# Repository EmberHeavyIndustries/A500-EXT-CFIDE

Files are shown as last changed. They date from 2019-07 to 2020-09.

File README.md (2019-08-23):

**A500-EXT-CFIDE** is an external IDE + Fast Memory Expansion for Amiga 500. 

It is basically a modified clone of Matthias Heinrich's CDTV-RAM-IDE board, targeted to be a quick & dirt solution for external A500/A1000 bootable mass storage (with the bonus of a RAM expansion if fitted).

The firmware is a customized version of original Matthias code, and comes thank to the wonderful kindness of Matthias himself, who put the effort and coded this derivative one as well. Thanks Matthias ! 

Within repository full schematics, board, gerbers and firmware code can be found free for everyone.
Please note that rev.1.0 board (the current one) has not been optimized against design rules, so though the project has been tested and proved fully working, a further rev.1.1 board will be released in next future, addressing all desgin "misbehaviours".

**License**

**A500-EXT-CFIDE** is Open Hardware. If you make any modifications to the board, please contribute them back.
Any derivative work must quote both the original author (Matthias Heinrich aka Matze) and EmberHeavyIndustries.

**Disclaimer**

**A500-EXT-CFIDE** is provided to you 'as is' and without any express or implied warranties whatsoever with respect to its functionality, operability or use, including, without limitation, any implied warranties of merchantability, fitness for a particular purpose or infringement. We expressly disclaim any liability whatsoever for any direct, indirect, consequential, incidental or special damages, including, without limitation, lost revenues, lost profits, losses resulting from business interruption or loss of data, regardless of the form of action or legal theory under which the liability may be asserted, even if advised of the possibility or likelihood of such damages.

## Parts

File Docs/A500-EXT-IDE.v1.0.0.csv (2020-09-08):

Part | Value | Device | Package | Description | MF | MPN | OC_FARNELL | OC_NEWARK
AUTOBOOT_OFF |  | JP1E | JP1 | JUMPER
C1 | 100n | C-EUC0603K | C0603K | CAPACITOR, European symbol
C2 | 100n | C-EUC0603K | C0603K | CAPACITOR, European symbol
C3 | 10u | C-EUC0805K | C0805K | CAPACITOR, European symbol
C4 | 10u | C-EUC0805K | C0805K | CAPACITOR, European symbol
C5 | 100n | C-EUC0603K | C0603K | CAPACITOR, European symbol
C6 | 10u | C-EUC0805K | C0805K | CAPACITOR, European symbol
C7 | 100n | C-EUC0603K | C0603K | CAPACITOR, European symbol
C8 | 100n | C-EUC0603K | C0603K | CAPACITOR, European symbol
C9 | 100n | C-EUC0603K | C0603K | CAPACITOR, European symbol
C10 | 100n | C-EUC0603K | C0603K | CAPACITOR, European symbol
C11 | 100n | C-EUC0603K | C0603K | CAPACITOR, European symbol
C12 | 100n | C-EUC0603K | C0603K | CAPACITOR, European symbol
CN1 | A500-EXPANSION-SLOT-SOLDER | A500-EXPANSION-SLOT-SOLDER | LKONT_43-SLOT-SOLDER
IC2 | XC95288XL-TQ144 | XC95288XL-TQ144 | TQFP144
IC3 | 74HCT245PW | 74HCT245PW | TSSOP20 | Octal BUS TRANSCEIVER, 3-state
IC4 | 74HCT245PW | 74HCT245PW | TSSOP20 | Octal BUS TRANSCEIVER, 3-state
IC5 | 74HCT245PW | 74HCT245PW | TSSOP20 | Octal BUS TRANSCEIVER, 3-state
IC6 | AS4C4M16S-6TCN | AS4C4M16S-6TCN | TSOP-2_54
IC7 | LD117AS33TR | LD117AS33TR | SOT223 | Low drop fixed and adjustable positive voltage regulators 1 A
IC8 | AM29F010J-SOCKET | AM29F010J-SOCKET | PLCC-32-SMT-TT | 1-Megabit FLASH MEMORY
IC10 | 50MHz | CSX-750FCFC(5V) | 7X5 | CITIZEN Crystal Clock Oscilator from http://cfm.citizen.co.jp/english/product/pdf/CSX-750F.pdf
JP1 |  | JP1E | JP1 | JUMPER
JP2 |  | JP1E | JP1 | JUMPER
MEM_OFF |  | JP1E | JP1 | JUMPER
R1 | 330 | R-EU_R0603 | R0603 | RESISTOR, European symbol
R2 | 4.7k | R-EU_R0603 | R0603 | RESISTOR, European symbol
R3 | 4.7k | R-EU_R0603 | R0603 | RESISTOR, European symbol
R4 | 4.7k | R-EU_R0603 | R0603 | RESISTOR, European symbol
R5 | 4.7k | R-EU_R0603 | R0603 | RESISTOR, European symbol
R6 | 4.7k | R-EU_R0603 | R0603 | RESISTOR, European symbol
R7 | 750mA | R-EU_R2512 | R2512 | RESISTOR, European symbol
R8 | FERRITE | R-EU_R0603 | R0603 | RESISTOR, European symbol
R9 | 47 | R-EU_R0603 | R0603 | RESISTOR, European symbol
RN1 | 33 | 4R-NCAY16 | CAY16 | Array Chip Resistor |  |  | unknown | unknown
RN2 | 33 | 4R-NCAY16 | CAY16 | Array Chip Resistor |  |  | unknown | unknown
RN3 | 33 | 4R-NCAY16 | CAY16 | Array Chip Resistor |  |  | unknown | unknown
RN4 | 33 | 4R-NCAY16 | CAY16 | Array Chip Resistor |  |  | unknown | unknown
RN5 | 33 | 4R-NCAY16 | CAY16 | Array Chip Resistor |  |  | unknown | unknown
RN6 | 4.7k | 4R-NCAY16 | CAY16 | Array Chip Resistor |  |  | unknown | unknown
RN7 | 33 | 4R-NCAY16 | CAY16 | Array Chip Resistor |  |  | unknown | unknown
RN8 | 33 | 4R-NCAY16 | CAY16 | Array Chip Resistor |  |  | unknown | unknown
RN9 | 33 | 4R-NCAY16 | CAY16 | Array Chip Resistor |  |  | unknown | unknown
RN10 | 33 | 4R-NCAY16 | CAY16 | Array Chip Resistor |  |  | unknown | unknown
RN11 | 33 | 4R-NCAY16 | CAY16 | Array Chip Resistor |  |  | unknown | unknown
SV1 |  | ML40 | ML40 | HARTING |  |  | unknown | unknown
SV2 |  | ML10L | ML10L | HARTING |  |  | unknown | unknown

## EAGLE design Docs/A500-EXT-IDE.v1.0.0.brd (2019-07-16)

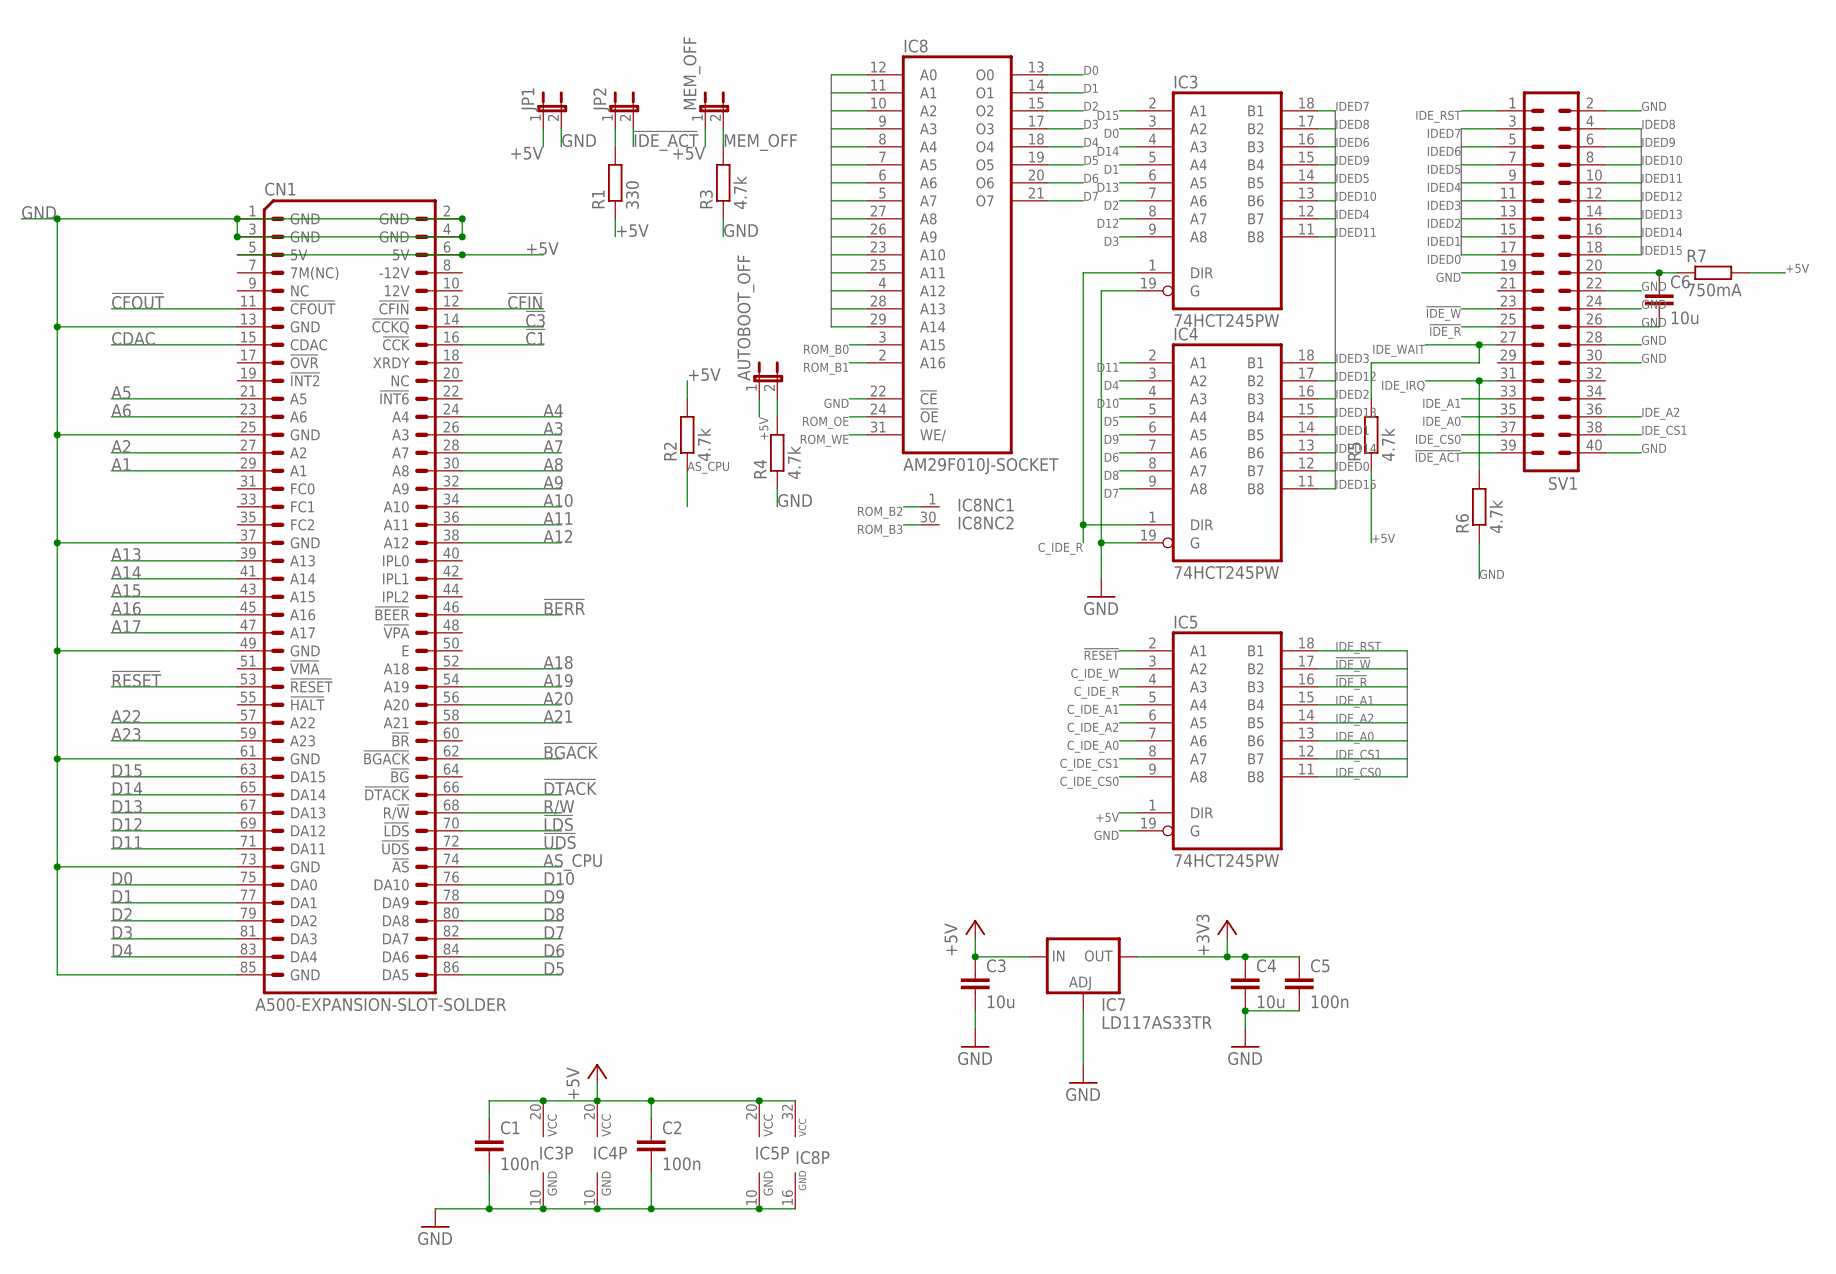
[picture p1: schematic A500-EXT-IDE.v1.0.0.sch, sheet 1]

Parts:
AUTOBOOT_OFF: JP1E; JP1
C1, C2, C5: 100n; C0603K
C3, C4, C6: 10u; C0805K
CN1: A500-EXPANSION-SLOT-SOLDER; LKONT_43-SLOT-SOLDER
IC3, IC4, IC5: 74HCT245PW; TSSOP20
IC7: LD117AS33TR; SOT223
IC8: AM29F010J-SOCKET; PLCC-32-SMT-TT
JP1, JP2: JP1E; JP1
MEM_OFF: JP1E; JP1
R1: 330; R0603
R2, R3, R4, R5, R6: 4.7k; R0603
R7: 750mA; R2512
SV1: ML40

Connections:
!BERR: CN1.46 (!BEER!); also elsewhere on the board
!BGACK: CN1.62 (!BGACK!); also elsewhere on the board
!C1: CN1.16 (!CCK!); also elsewhere on the board
!C3: CN1.14 (!CCKQ!); also elsewhere on the board
!CFIN: CN1.12 (!CFIN!); also elsewhere on the board
!CFOUT: CN1.11 (!CFOUT!); also elsewhere on the board
!DTACK: CN1.66 (!DTACK!); also elsewhere on the board
!IDE_ACT: JP2.2, SV1.39
!IDE_R: IC5.16 (B3), SV1.25
!IDE_W: IC5.17 (B2), SV1.23
!LDS: CN1.70 (!LDS!); also elsewhere on the board
!RESET: CN1.53 (!RESET!), IC5.2 (A1); also elsewhere on the board
!UDS: CN1.72 (!UDS!); also elsewhere on the board
+3V3: C4.1, C5.1, IC7.2 (OUT), IC7.4 (OUT); also elsewhere on the board
+5V: AUTOBOOT_OFF.1, C1.1, C2.1, C3.1, CN1.5 (5V), CN1.6 (5V), IC3.20 (VCC), IC4.20 (VCC), IC5.1 (DIR), IC5.20 (VCC), IC7.3 (IN), IC8.32 (VCC), JP1.1, MEM_OFF.1, R1.1, R2.2, R5.1, R7.2; also elsewhere on the board
A1: CN1.29 (A1), IC8.12 (A0); also elsewhere on the board
A2: CN1.27 (A2), IC8.11 (A1); also elsewhere on the board
A3: CN1.26 (A3), IC8.10 (A2); also elsewhere on the board
A4: CN1.24 (A4), IC8.9 (A3); also elsewhere on the board
A5: CN1.21 (A5), IC8.8 (A4); also elsewhere on the board
A6: CN1.23 (A6), IC8.7 (A5); also elsewhere on the board
A7: CN1.28 (A7), IC8.6 (A6); also elsewhere on the board
A8: CN1.30 (A8), IC8.5 (A7); also elsewhere on the board
A9: CN1.32 (A9), IC8.27 (A8); also elsewhere on the board
A10: CN1.34 (A10), IC8.26 (A9); also elsewhere on the board
A11: CN1.36 (A11), IC8.23 (A10); also elsewhere on the board
A12: CN1.38 (A12), IC8.25 (A11); also elsewhere on the board
A13: CN1.39 (A13), IC8.4 (A12); also elsewhere on the board
A14: CN1.41 (A14), IC8.28 (A13); also elsewhere on the board
A15: CN1.43 (A15), IC8.29 (A14); also elsewhere on the board
A16: CN1.45 (A16); also elsewhere on the board
A17: CN1.47 (A17); also elsewhere on the board
A18: CN1.52 (A18); also elsewhere on the board
A19: CN1.54 (A19); also elsewhere on the board
A20: CN1.56 (A20); also elsewhere on the board
A21: CN1.58 (A21); also elsewhere on the board
A22: CN1.57 (A22); also elsewhere on the board
A23: CN1.59 (A23); also elsewhere on the board
AS_CPU: CN1.74 (!AS!), R2.1; also elsewhere on the board
AUTO_BOOT_OFF: AUTOBOOT_OFF.2, R4.2; also elsewhere on the board
CDAC: CN1.15 (CDAC); also elsewhere on the board
C_IDE_A0: IC5.7 (A6); also elsewhere on the board
C_IDE_A1: IC5.5 (A4); also elsewhere on the board
C_IDE_A2: IC5.6 (A5); also elsewhere on the board
C_IDE_CS0: IC5.9 (A8); also elsewhere on the board
C_IDE_CS1: IC5.8 (A7); also elsewhere on the board
C_IDE_R: IC3.1 (DIR), IC4.1 (DIR), IC5.4 (A3); also elsewhere on the board
C_IDE_W: IC5.3 (A2); also elsewhere on the board
D0: CN1.75 (DA0), IC3.3 (A2), IC8.13 (O0); also elsewhere on the board
D1: CN1.77 (DA1), IC3.5 (A4), IC8.14 (O1); also elsewhere on the board
D2: CN1.79 (DA2), IC3.7 (A6), IC8.15 (O2); also elsewhere on the board
D3: CN1.81 (DA3), IC3.9 (A8), IC8.17 (O3); also elsewhere on the board
D4: CN1.83 (DA4), IC4.3 (A2), IC8.18 (O4); also elsewhere on the board
D5: CN1.86 (DA5), IC4.5 (A4), IC8.19 (O5); also elsewhere on the board
D6: CN1.84 (DA6), IC4.7 (A6), IC8.20 (O6); also elsewhere on the board
D7: CN1.82 (DA7), IC4.9 (A8), IC8.21 (O7); also elsewhere on the board
D8: CN1.80 (DA8), IC4.8 (A7); also elsewhere on the board
D9: CN1.78 (DA9), IC4.6 (A5); also elsewhere on the board
D10: CN1.76 (DA10), IC4.4 (A3); also elsewhere on the board
D11: CN1.71 (DA11), IC4.2 (A1); also elsewhere on the board
D12: CN1.69 (DA12), IC3.8 (A7); also elsewhere on the board
D13: CN1.67 (DA13), IC3.6 (A5); also elsewhere on the board
D14: CN1.65 (DA14), IC3.4 (A3); also elsewhere on the board
D15: CN1.63 (DA15), IC3.2 (A1); also elsewhere on the board
GND: C1.2, C2.2, C3.2, C4.2, C5.2, C6.2, CN1.1 (GND), CN1.2 (GND), CN1.3 (GND), CN1.4 (GND), CN1.13 (GND), CN1.25 (GND), CN1.37 (GND), CN1.49 (GND), CN1.61 (GND), CN1.73 (GND), CN1.85 (GND), IC3.10 (GND), IC3.19 (G), IC4.10 (GND), IC4.19 (G), IC5.10 (GND), IC5.19 (G), IC7.1 (ADJ), IC8.16 (GND), IC8.22 (!CE), JP1.2, R3.1, R4.1, R6.1, SV1.2, SV1.19, SV1.22, SV1.24, SV1.26, SV1.28, SV1.30, SV1.40; also elsewhere on the board
IDED0: IC4.12 (B7), SV1.17
IDED1: IC4.14 (B5), SV1.15
IDED2: IC4.16 (B3), SV1.13
IDED3: IC4.18 (B1), SV1.11
IDED4: IC3.12 (B7), SV1.9
IDED5: IC3.14 (B5), SV1.7
IDED6: IC3.16 (B3), SV1.5
IDED7: IC3.18 (B1), SV1.3
IDED8: IC3.17 (B2), SV1.4
IDED9: IC3.15 (B4), SV1.6
IDED10: IC3.13 (B6), SV1.8
IDED11: IC3.11 (B8), SV1.10
IDED12: IC4.17 (B2), SV1.12
IDED13: IC4.15 (B4), SV1.14
IDED14: IC4.13 (B6), SV1.16
IDED15: IC4.11 (B8), SV1.18
IDE_A0: IC5.13 (B6), SV1.35
IDE_A1: IC5.15 (B4), SV1.33
IDE_A2: IC5.14 (B5), SV1.36
IDE_CS0: IC5.11 (B8), SV1.37
IDE_CS1: IC5.12 (B7), SV1.38
IDE_IRQ: R6.2, SV1.31; also elsewhere on the board
IDE_RST: IC5.18 (B1), SV1.1
IDE_WAIT: R5.2, SV1.27; also elsewhere on the board
KEY_PIN_POWER: C6.1, R7.1, SV1.20
MEM_OFF: MEM_OFF.2, R3.2; also elsewhere on the board
unnamed: JP2.1, R1.2
R/W: CN1.68 (R/!W!); also elsewhere on the board
ROM_B0: IC8.3 (A15); also elsewhere on the board
ROM_B1: IC8.2 (A16); also elsewhere on the board
ROM_B2: IC8.1 (NC); also elsewhere on the board
ROM_B3: IC8.30 (NC); also elsewhere on the board
ROM_OE: IC8.24 (!OE); also elsewhere on the board
ROM_WE: IC8.31 (WE/); also elsewhere on the board

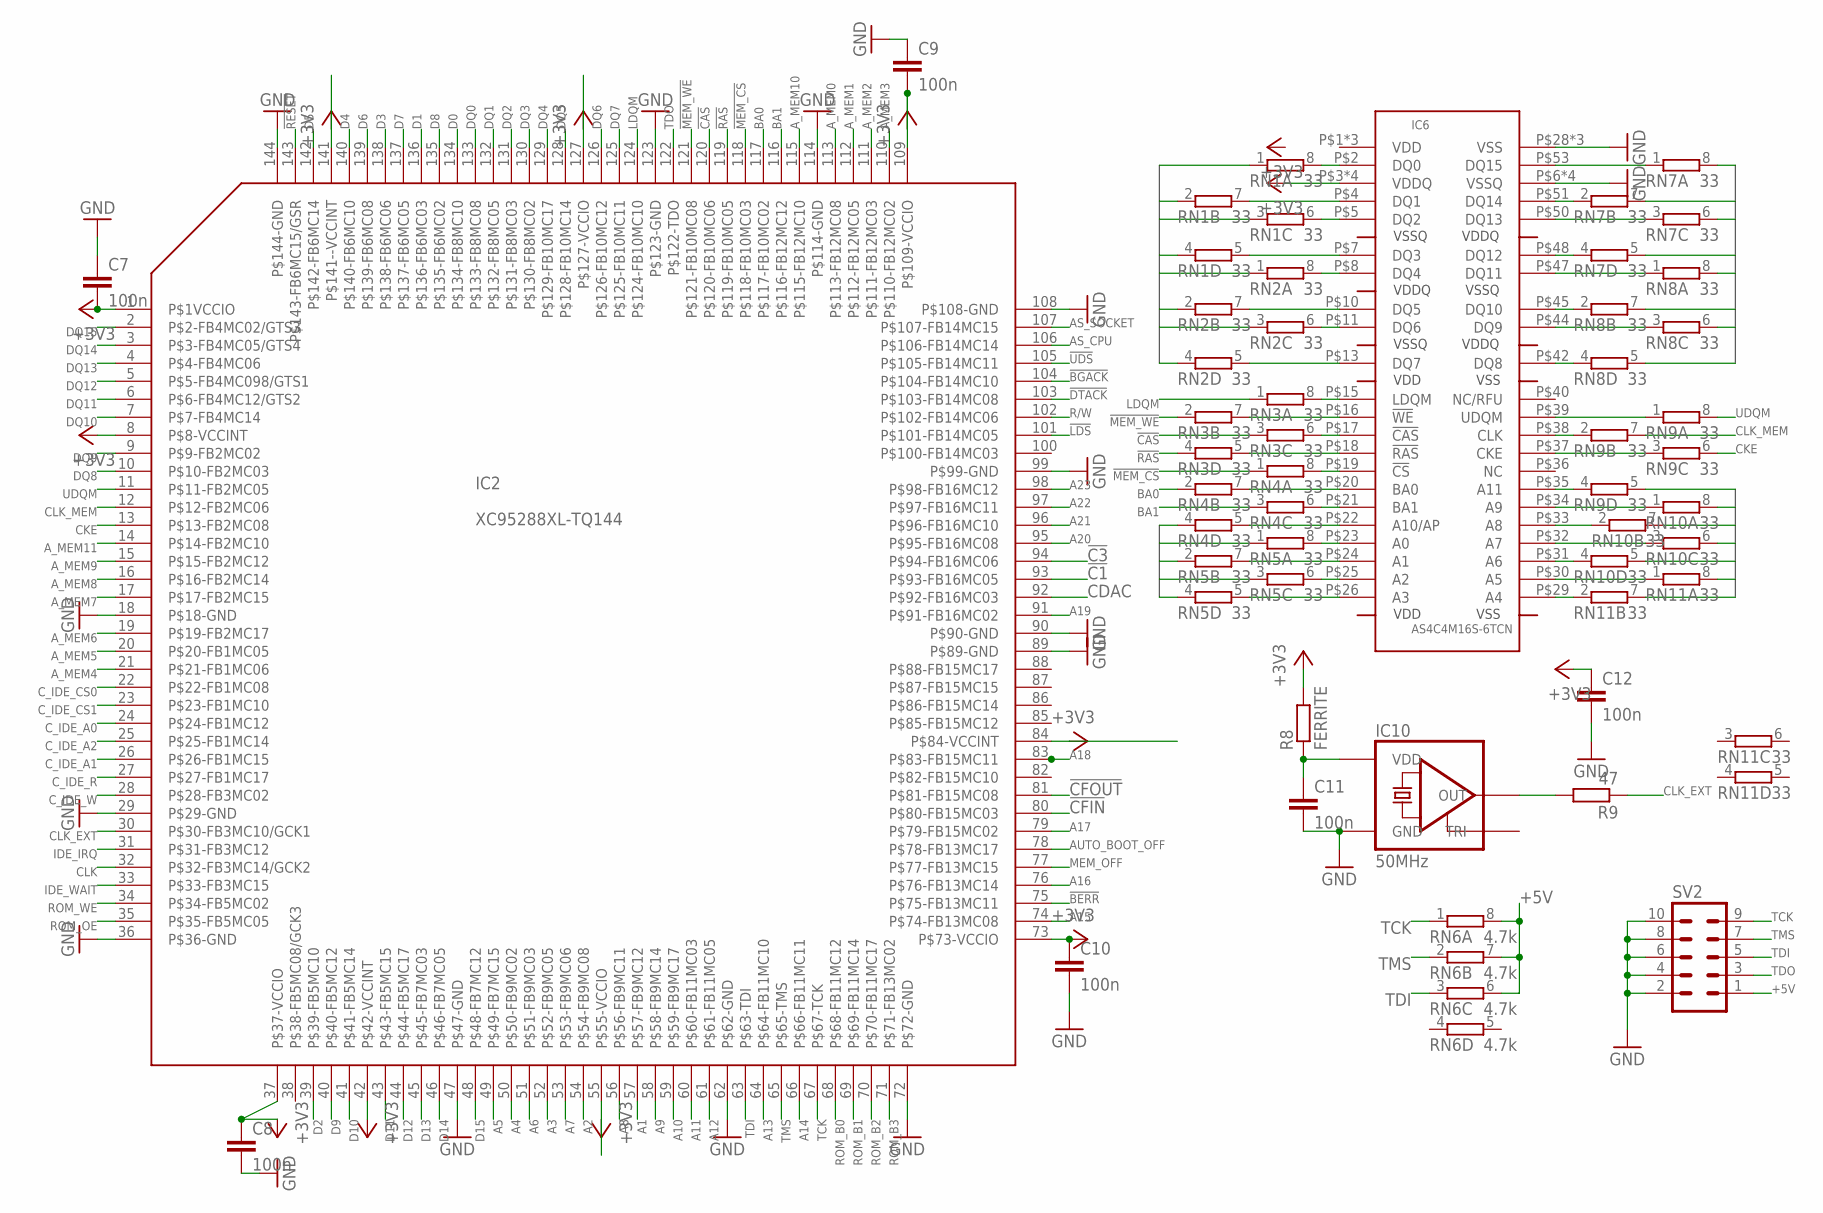
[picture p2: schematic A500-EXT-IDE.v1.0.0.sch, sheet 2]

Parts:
C7, C8, C9, C10, C11, C12: 100n; C0603K
IC2: XC95288XL-TQ144; TQFP144
IC6: AS4C4M16S-6TCN; TSOP-2_54
IC10: 50MHz; 7X5
R8: FERRITE; R0603
R9: 47; R0603
RN1, RN2, RN3, RN4, RN5, RN7, RN8, RN9, RN10, RN11: 33; CAY16
RN6: 4.7k; CAY16
SV2: ML10L

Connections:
!BERR: IC2.75 (P$75-FB13MC11); also elsewhere on the board
!BGACK: IC2.104 (P$104-FB14MC10); also elsewhere on the board
!C1: IC2.93 (P$93-FB16MC05); also elsewhere on the board
!C3: IC2.94 (P$94-FB16MC06); also elsewhere on the board
!CAS: IC2.120 (P$120-FB10MC06), RN3.3 (1)
!CFIN: IC2.80 (P$80-FB15MC03); also elsewhere on the board
!CFOUT: IC2.81 (P$81-FB15MC08); also elsewhere on the board
!DTACK: IC2.103 (P$103-FB14MC08); also elsewhere on the board
!LDS: IC2.101 (P$101-FB14MC05); also elsewhere on the board
!MEM_CS: IC2.118 (P$118-FB10MC03), RN4.1
!MEM_WE: IC2.121 (P$121-FB10MC08), RN3.2 (1)
!RAS: IC2.119 (P$119-FB10MC05), RN3.4 (1)
!RESET: IC2.143 (P$143-FB6MC15/GSR); also elsewhere on the board
!UDS: IC2.105 (P$105-FB14MC11); also elsewhere on the board
+3V3: C7.2, C8.1, C9.2, C10.1, C12.1, IC2.1 (P$1VCCIO), IC2.8 (P$8-VCCINT), IC2.37 (P$37-VCCIO), IC2.42 (P$42-VCCINT), IC2.55 (P$55-VCCIO), IC2.73 (P$73-VCCIO), IC2.84 (P$84-VCCINT), IC2.109 (P$109-VCCIO), IC2.127 (P$127-VCCIO), IC2.141 (P$141--VCCINT), IC6.P$3 (VDDQ), IC6.P$9 (VDDQ), IC6.P$43 (VDDQ), IC6.P$49 (VDDQ), R8.2; also elsewhere on the board
+5V: RN6.6 (2), RN6.7 (2), RN6.8 (2), SV2.1; also elsewhere on the board
A1: IC2.57 (P$57-FB9MC12); also elsewhere on the board
A2: IC2.54 (P$54-FB9MC08); also elsewhere on the board
A3: IC2.52 (P$52-FB9MC05); also elsewhere on the board
A4: IC2.50 (P$50-FB9MC02); also elsewhere on the board
A5: IC2.49 (P$49-FB7MC15); also elsewhere on the board
A6: IC2.51 (P$51-FB9MC03); also elsewhere on the board
A7: IC2.53 (P$53-FB9MC06); also elsewhere on the board
A8: IC2.56 (P$56-FB9MC11); also elsewhere on the board
A9: IC2.58 (P$58-FB9MC14); also elsewhere on the board
A10: IC2.59 (P$59-FB9MC17); also elsewhere on the board
A11: IC2.60 (P$60-FB11MC03); also elsewhere on the board
A12: IC2.61 (P$61-FB11MC05); also elsewhere on the board
A13: IC2.64 (P$64-FB11MC10); also elsewhere on the board
A14: IC2.66 (P$66-FB11MC11); also elsewhere on the board
A15: IC2.74 (P$74-FB13MC08); also elsewhere on the board
A16: IC2.76 (P$76-FB13MC14); also elsewhere on the board
A17: IC2.79 (P$79-FB15MC02); also elsewhere on the board
A18: IC2.83 (P$83-FB15MC11); also elsewhere on the board
A19: IC2.91 (P$91-FB16MC02); also elsewhere on the board
A20: IC2.95 (P$95-FB16MC08); also elsewhere on the board
A21: IC2.96 (P$96-FB16MC10); also elsewhere on the board
A22: IC2.97 (P$97-FB16MC11); also elsewhere on the board
A23: IC2.98 (P$98-FB16MC12); also elsewhere on the board
AS_CPU: IC2.106 (P$106-FB14MC14); also elsewhere on the board
AS_SOCKET: IC2.107 (P$107-FB14MC15)
AUTO_BOOT_OFF: IC2.78 (P$78-FB13MC17); also elsewhere on the board
A_MEM0: IC2.113 (P$113-FB12MC08), RN5.1
A_MEM1: IC2.112 (P$112-FB12MC05), RN5.2 (1)
A_MEM2: IC2.111 (P$111-FB12MC03), RN5.3 (1)
A_MEM3: IC2.110 (P$110-FB12MC02), RN5.4 (1)
A_MEM4: IC2.21 (P$21-FB1MC06), RN11.7 (2)
A_MEM5: IC2.20 (P$20-FB1MC05), RN11.8 (2)
A_MEM6: IC2.19 (P$19-FB2MC17), RN10.5 (2)
A_MEM7: IC2.17 (P$17-FB2MC15), RN10.6 (2)
A_MEM8: IC2.16 (P$16-FB2MC14), RN10.7 (2)
A_MEM9: IC2.15 (P$15-FB2MC12), RN10.8 (2)
A_MEM10: IC2.115 (P$115-FB12MC10), RN4.4 (1)
A_MEM11: IC2.14 (P$14-FB2MC10), RN9.5 (2)
BA0: IC2.117 (P$117-FB10MC02), RN4.2 (1)
BA1: IC2.116 (P$116-FB12MC12), RN4.3 (1)
CDAC: IC2.92 (P$92-FB16MC03); also elsewhere on the board
CKE: IC2.13 (P$13-FB2MC08), RN9.6 (2)
CLK: IC2.32 (P$32-FB3MC14/GCK2)
CLK_EXT: IC2.30 (P$30-FB3MC10/GCK1), R9.1
CLK_MEM: IC2.12 (P$12-FB2MC06), RN9.7 (2)
C_IDE_A0: IC2.24 (P$24-FB1MC12); also elsewhere on the board
C_IDE_A1: IC2.26 (P$26-FB1MC15); also elsewhere on the board
C_IDE_A2: IC2.25 (P$25-FB1MC14); also elsewhere on the board
C_IDE_CS0: IC2.22 (P$22-FB1MC08); also elsewhere on the board
C_IDE_CS1: IC2.23 (P$23-FB1MC10); also elsewhere on the board
C_IDE_R: IC2.27 (P$27-FB1MC17); also elsewhere on the board
C_IDE_W: IC2.28 (P$28-FB3MC02); also elsewhere on the board
D0: IC2.134 (P$134-FB8MC10); also elsewhere on the board
D1: IC2.136 (P$136-FB6MC03); also elsewhere on the board
D2: IC2.39 (P$39-FB5MC10); also elsewhere on the board
D3: IC2.138 (P$138-FB6MC06); also elsewhere on the board
D4: IC2.140 (P$140-FB6MC10); also elsewhere on the board
D5: IC2.142 (P$142-FB6MC14); also elsewhere on the board
D6: IC2.139 (P$139-FB6MC08); also elsewhere on the board
D7: IC2.137 (P$137-FB6MC05); also elsewhere on the board
D8: IC2.135 (P$135-FB6MC02); also elsewhere on the board
D9: IC2.40 (P$40-FB5MC12); also elsewhere on the board
D10: IC2.41 (P$41-FB5MC14); also elsewhere on the board
D11: IC2.43 (P$43-FB5MC15); also elsewhere on the board
D12: IC2.44 (P$44-FB5MC17); also elsewhere on the board
D13: IC2.45 (P$45-FB7MC03); also elsewhere on the board
D14: IC2.46 (P$46-FB7MC05); also elsewhere on the board
D15: IC2.48 (P$48-FB7MC12); also elsewhere on the board
DQ0: IC2.133 (P$133-FB8MC08), RN1.1
DQ1: IC2.132 (P$132-FB8MC05), RN1.2 (1)
DQ2: IC2.131 (P$131-FB8MC03), RN1.3 (1)
DQ3: IC2.130 (P$130-FB8MC02), RN1.4 (1)
DQ4: IC2.129 (P$129-FB10MC17), RN2.1
DQ5: IC2.128 (P$128-FB10MC14), RN2.2 (1)
DQ6: IC2.126 (P$126-FB10MC12), RN2.3 (1)
DQ7: IC2.125 (P$125-FB10MC11), RN2.4 (1)
DQ8: IC2.10 (P$10-FB2MC03), RN8.5 (2)
DQ9: IC2.9 (P$9-FB2MC02), RN8.6 (2)
DQ10: IC2.7 (P$7-FB4MC14), RN8.7 (2)
DQ11: IC2.6 (P$6-FB4MC12/GTS2), RN8.8 (2)
DQ12: IC2.5 (P$5-FB4MC098/GTS1), RN7.5 (2)
DQ13: IC2.4 (P$4-FB4MC06), RN7.6 (2)
DQ14: IC2.3 (P$3-FB4MC05/GTS4), RN7.7 (2)
DQ15: IC2.2 (P$2-FB4MC02/GTS3), RN7.8 (2)
GND: C7.1, C8.2, C9.1, C10.2, C11.2, C12.2, IC2.18 (P$18-GND), IC2.29 (P$29-GND), IC2.36 (P$36-GND), IC2.47 (P$47-GND), IC2.62 (P$62-GND), IC2.72 (P$72-GND), IC2.89 (P$89-GND), IC2.90 (P$90-GND), IC2.99 (P$99-GND), IC2.108 (P$108-GND), IC2.114 (P$114-GND), IC2.123 (P$123-GND), IC2.144 (P$144-GND), IC6.P$6 (VSSQ), IC6.P$12 (VSSQ), IC6.P$28 (VSS), IC6.P$41 (VSS), IC6.P$46 (VSSQ), IC6.P$52 (VSSQ), IC6.P$54 (VSS), IC10.P$2 (GND), SV2.2, SV2.4, SV2.6, SV2.8, SV2.10; also elsewhere on the board
IDE_IRQ: IC2.31 (P$31-FB3MC12); also elsewhere on the board
IDE_WAIT: IC2.33 (P$33-FB3MC15); also elsewhere on the board
LDQM: IC2.124 (P$124-FB10MC10), RN3.1
MEM_OFF: IC2.77 (P$77-FB13MC15); also elsewhere on the board
unnamed: IC6.P$26 (A3), RN5.5 (2)
unnamed: IC6.P$25 (A2), RN5.6 (2)
unnamed: IC6.P$24 (A1), RN5.7 (2)
unnamed: IC6.P$23 (A0), RN5.8 (2)
unnamed: IC6.P$22 (A10/AP), RN4.5 (2)
unnamed: IC6.P$21 (BA1), RN4.6 (2)
unnamed: IC6.P$20 (BA0), RN4.7 (2)
unnamed: IC6.P$19 (!CS), RN4.8 (2)
unnamed: IC6.P$18 (!RAS), RN3.5 (2)
unnamed: IC6.P$17 (!CAS), RN3.6 (2)
unnamed: IC6.P$16 (!WE), RN3.7 (2)
unnamed: IC6.P$15 (LDQM), RN3.8 (2)
unnamed: IC6.P$13 (DQ7), RN2.5 (2)
unnamed: IC6.P$11 (DQ6), RN2.6 (2)
unnamed: IC6.P$10 (DQ5), RN2.7 (2)
unnamed: IC6.P$8 (DQ4), RN2.8 (2)
unnamed: IC6.P$7 (DQ3), RN1.5 (2)
unnamed: IC6.P$5 (DQ2), RN1.6 (2)
unnamed: IC6.P$4 (DQ1), RN1.7 (2)
unnamed: IC6.P$2 (DQ0), RN1.8 (2)
unnamed: IC6.P$53 (DQ15), RN7.1
unnamed: IC6.P$51 (DQ14), RN7.2 (1)
unnamed: IC6.P$50 (DQ13), RN7.3 (1)
unnamed: IC6.P$48 (DQ12), RN7.4 (1)
unnamed: IC6.P$47 (DQ11), RN8.1
unnamed: IC6.P$45 (DQ10), RN8.2 (1)
unnamed: IC6.P$44 (DQ9), RN8.3 (1)
unnamed: IC6.P$42 (DQ8), RN8.4 (1)
unnamed: IC6.P$39 (UDQM), RN9.1
unnamed: IC6.P$38 (CLK), RN9.2 (1)
unnamed: IC6.P$37 (CKE), RN9.3 (1)
unnamed: IC6.P$35 (A11), RN9.4 (1)
unnamed: IC6.P$34 (A9), RN10.1
unnamed: IC6.P$33 (A8), RN10.2 (1)
unnamed: IC6.P$32 (A7), RN10.3 (1)
unnamed: IC6.P$31 (A6), RN10.4 (1)
unnamed: IC6.P$30 (A5), RN11.1
unnamed: IC6.P$29 (A4), RN11.2 (1)
unnamed: IC10.P$3 (OUT), R9.2
R/W: IC2.102 (P$102-FB14MC06); also elsewhere on the board
ROM_B0: IC2.68 (P$68-FB11MC12); also elsewhere on the board
ROM_B1: IC2.69 (P$69-FB11MC14); also elsewhere on the board
ROM_B2: IC2.70 (P$70-FB11MC17); also elsewhere on the board
ROM_B3: IC2.71 (P$71-FB13MC02); also elsewhere on the board
ROM_OE: IC2.35 (P$35-FB5MC05); also elsewhere on the board
ROM_WE: IC2.34 (P$34-FB5MC02); also elsewhere on the board
TCK: IC2.67 (P$67-TCK), RN6.1, SV2.9
TDI: IC2.63 (P$63-TDI), RN6.3 (1), SV2.5
TDO: IC2.122 (P$122-TDO), SV2.3
TMS: IC2.65 (P$65-TMS), RN6.2 (1), SV2.7
UDQM: IC2.11 (P$11-FB2MC05), RN9.8 (2)
VCC-X: C11.1, IC10.P$4 (VDD), R8.1

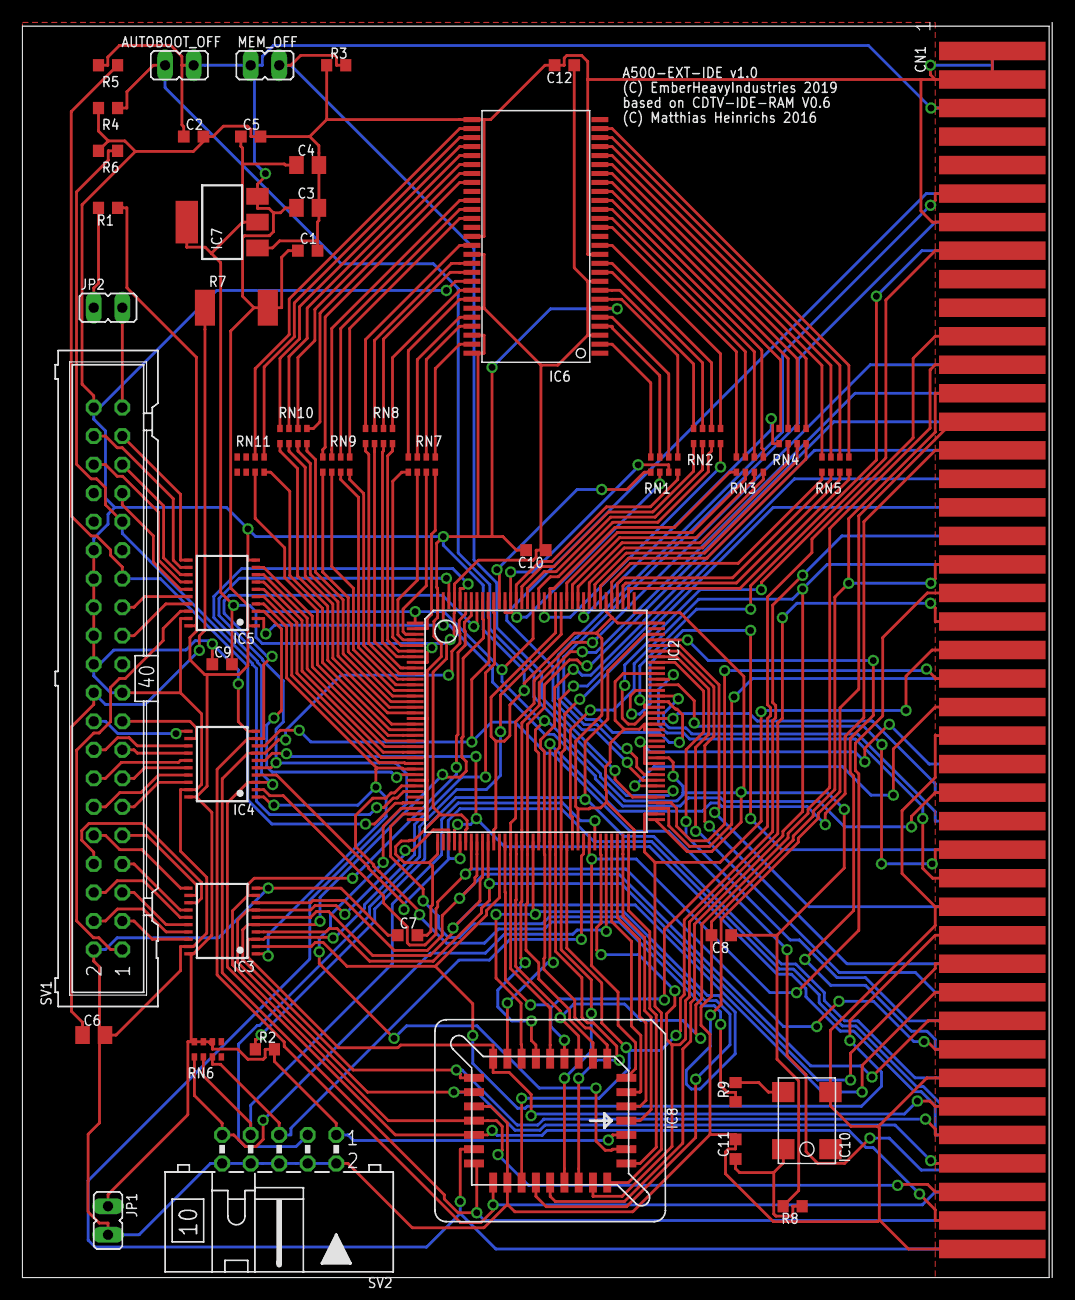
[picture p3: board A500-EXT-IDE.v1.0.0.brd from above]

Board: 2 copper layers, 91.4 x 111.4 mm, 47 parts (0 on the bottom side), 182 nets.

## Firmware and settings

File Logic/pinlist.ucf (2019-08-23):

#amiga busses
#amiga signals
#RAM signals
#IDE signals
#rom signals
#controll signals
#PACE: Start of Constraints generated by PACE

#PACE: Start of PACE I/O Pin Assignments
NET "A<1>"  LOC = "P57"  ; 
NET "A<2>"  LOC = "P54"  ; 
NET "A<3>"  LOC = "P52"  ; 
NET "A<4>"  LOC = "P50"  ; 
NET "A<5>"  LOC = "P49"  ; 
NET "A<6>"  LOC = "P51"  ; 
NET "A<7>"  LOC = "P53"  ; 
NET "A<8>"  LOC = "P56"  ; 
NET "A<9>"  LOC = "P58"  ; 
NET "A<10>"  LOC = "P59"  ; 
NET "A<11>"  LOC = "P60"  ; 
NET "A<12>"  LOC = "P61"  ; 
NET "A<13>"  LOC = "P64"  ; 
NET "A<14>"  LOC = "P66"  ; 
NET "A<15>"  LOC = "P74"  ; 
NET "A<16>"  LOC = "P76"  ; 
NET "A<17>"  LOC = "P79"  ; 
NET "A<18>"  LOC = "P83"  ; 
NET "A<19>"  LOC = "P91"  ; 
NET "A<20>"  LOC = "P95"  ; 
NET "A<21>"  LOC = "P96"  ; 
NET "A<22>"  LOC = "P97"  ; 
NET "A<23>"  LOC = "P98"  ; 
NET "C1"  LOC = "P93"  ; 
NET "C3"  LOC = "P94"  ; 
NET "CDAC"  LOC = "P92"  ; 
NET "ARAM<0>"  LOC = "P113"  ; 
NET "ARAM<1>"  LOC = "P112"  ; 
NET "ARAM<2>"  LOC = "P111"  ; 
NET "ARAM<3>"  LOC = "P110"  ; 
NET "ARAM<4>"  LOC = "P21"  ; 
NET "ARAM<5>"  LOC = "P20"  ; 
NET "ARAM<6>"  LOC = "P19"  ; 
NET "ARAM<7>"  LOC = "P17"  ; 
NET "ARAM<8>"  LOC = "P16"  ; 
NET "ARAM<9>"  LOC = "P15"  ; 
NET "ARAM<10>"  LOC = "P115"  ; 
NET "ARAM<11>"  LOC = "P14"  ; 
NET "AS"  LOC = "P106"  ; 
NET "BA<0>"  LOC = "P117"  ; 
NET "BA<1>"  LOC = "P116"  ; 
NET "BERR"  LOC = "P75"  ; 
NET "CAS"  LOC = "P120"  ; 
NET "CKE"  LOC = "P13"  ; 
NET "CLK50M"  LOC = "P30"  ; 
NET "CLK_MEM"  LOC = "P12"  ; 
NET "CF_IN"  LOC = "P80"  ; 
NET "CF_OUT"  LOC = "P81"  ; 
NET "D<0>"  LOC = "P134"  ; 
NET "D<1>"  LOC = "P136"  ; 
NET "D<2>"  LOC = "P39"  ; 
NET "D<3>"  LOC = "P138"  ; 
NET "D<4>"  LOC = "P140"  ; 
NET "D<5>"  LOC = "P142"  ; 
NET "D<6>"  LOC = "P139"  ; 
NET "D<7>"  LOC = "P137"  ; 
NET "D<8>"  LOC = "P135"  ; 
NET "D<9>"  LOC = "P40"  ; 
NET "D<10>"  LOC = "P41"  ; 
NET "D<11>"  LOC = "P43"  ; 
NET "D<12>"  LOC = "P44"  ; 
NET "D<13>"  LOC = "P45"  ; 
NET "D<14>"  LOC = "P46"  ; 
NET "D<15>"  LOC = "P48"  ; 
NET "DRAM<0>"  LOC = "P133"  ; 
NET "DRAM<1>"  LOC = "P132"  ; 
NET "DRAM<2>"  LOC = "P131"  ; 
NET "DRAM<3>"  LOC = "P130"  ; 
NET "DRAM<4>"  LOC = "P129"  ; 
NET "DRAM<5>"  LOC = "P128"  ; 
NET "DRAM<6>"  LOC = "P126"  ; 
NET "DRAM<7>"  LOC = "P125"  ; 
NET "DRAM<8>"  LOC = "P10"  ; 
NET "DRAM<9>"  LOC = "P9"  ; 
NET "DRAM<10>"  LOC = "P7"  ; 
NET "DRAM<11>"  LOC = "P6"  ; 
NET "DRAM<12>"  LOC = "P5"  ; 
NET "DRAM<13>"  LOC = "P4"  ; 
NET "DRAM<14>"  LOC = "P3"  ; 
NET "DRAM<15>"  LOC = "P2"  ; 
NET "DTACK"  LOC = "P103"  ; 
NET "IDE_A<0>"  LOC = "P24"  ; 
NET "IDE_A<1>"  LOC = "P26"  ; 
NET "IDE_A<2>"  LOC = "P25"  ; 
NET "IDE_CS<0>"  LOC = "P22"  ; 
NET "IDE_CS<1>"  LOC = "P23"  ; 
NET "IDE_IRQ"  LOC = "P31"  ; 
NET "IDE_OFF"  LOC = "P78"  ; 
NET "IDE_R"  LOC = "P27"  ; 
NET "IDE_W"  LOC = "P28"  ; 
NET "IDE_WAIT"  LOC = "P33"  ; 
NET "LDQM"  LOC = "P124"  ; 
NET "LDS"  LOC = "P101"  ; 
NET "MEM_CS"  LOC = "P118"  ; 
NET "MEM_OFF"  LOC = "P77"  ; 
NET "MEM_WE"  LOC = "P121"  ; 
NET "RAS"  LOC = "P119"  ; 
NET "RESET"  LOC = "P143"  ; 
NET "ROM_BANK<0>"  LOC = "P68"  ; 
NET "ROM_BANK<1>"  LOC = "P69"  ; 
NET "ROM_BANK<2>"  LOC = "P71"  ; 
NET "ROM_BANK<3>"  LOC = "P70"  ; 
NET "ROM_OE"  LOC = "P35"  ; 
NET "ROM_WE"  LOC = "P34"  ; 
NET "RW"  LOC = "P102"  ; 
NET "UDQM"  LOC = "P11"  ; 
NET "UDS"  LOC = "P105"  ; 

#PACE: Start of PACE Area Constraints

#PACE: Start of PACE Prohibit Constraints

#PACE: End of Constraints generated by PACE
